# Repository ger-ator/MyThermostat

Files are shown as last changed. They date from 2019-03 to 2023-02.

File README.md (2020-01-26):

# MyThermostat

MyThermostat is a drop-in replacement board for Farho Xana Plus oil heater.

Provided sketch is a thermostat node draft for MySensors network.

## Features
- ATMega328P makes it Arduino compatible.
- RFM69 for extended range.
- ATSHA204 for hardware signing.
- AT25DF512C FOTA programming enabled.
- Onboard DS18B20 for temperature protection purposes.
- 0,96" Oled display.
- Linear power supply, so no pitch noise around bedroom.
- Power SSR with built-in heatsink. No switching noise.
- Uses the original 2x2 keypad for user interaction.

The board is exactly the same form factor as the factory one so it can be mounted without modifying the original frame. Just unplug the old board and drop-in the new one. The goal is to keep heater modifications as low as possible.

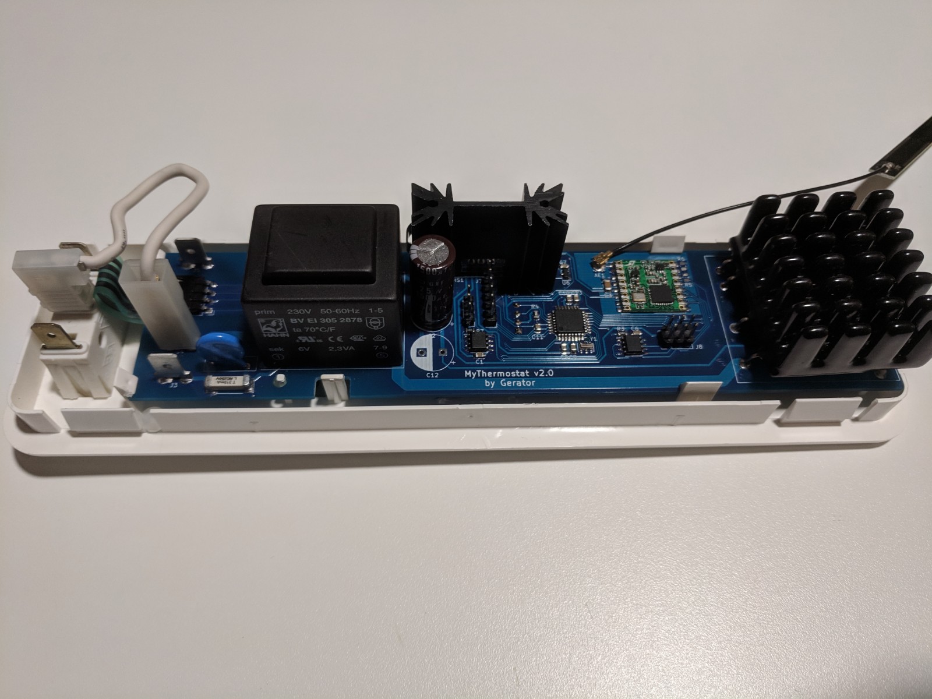
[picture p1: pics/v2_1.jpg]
MyThermostat board


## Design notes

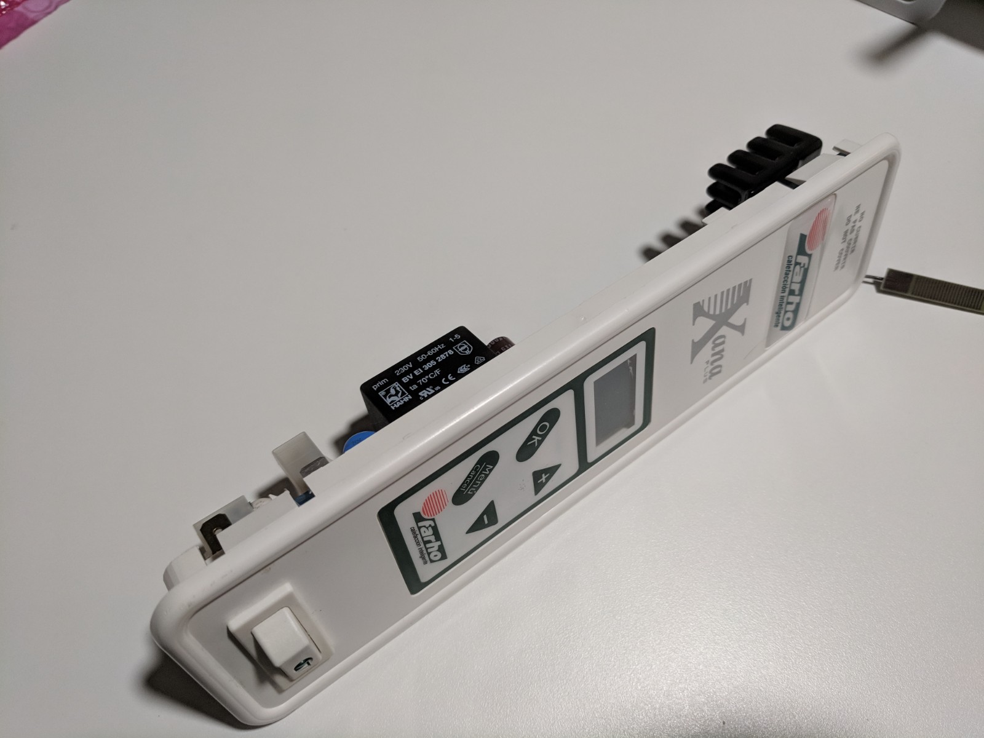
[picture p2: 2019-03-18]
pics/v2_2.jpg

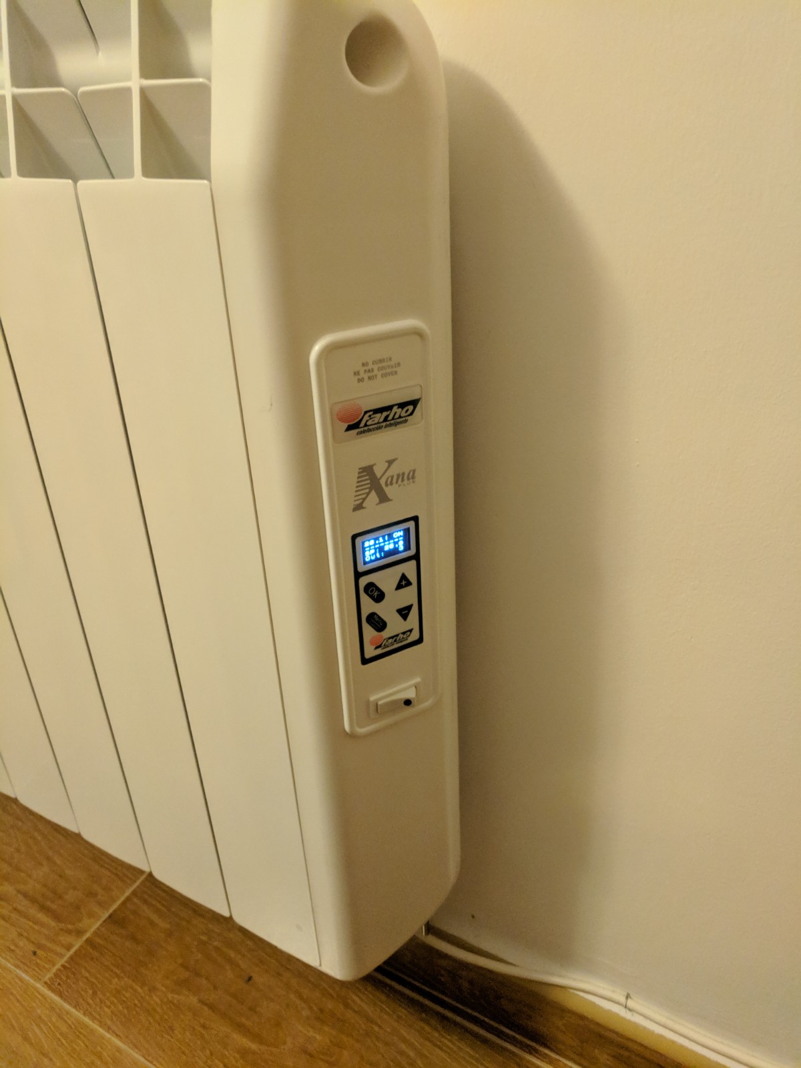
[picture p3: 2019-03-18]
pics/v2_3.jpg

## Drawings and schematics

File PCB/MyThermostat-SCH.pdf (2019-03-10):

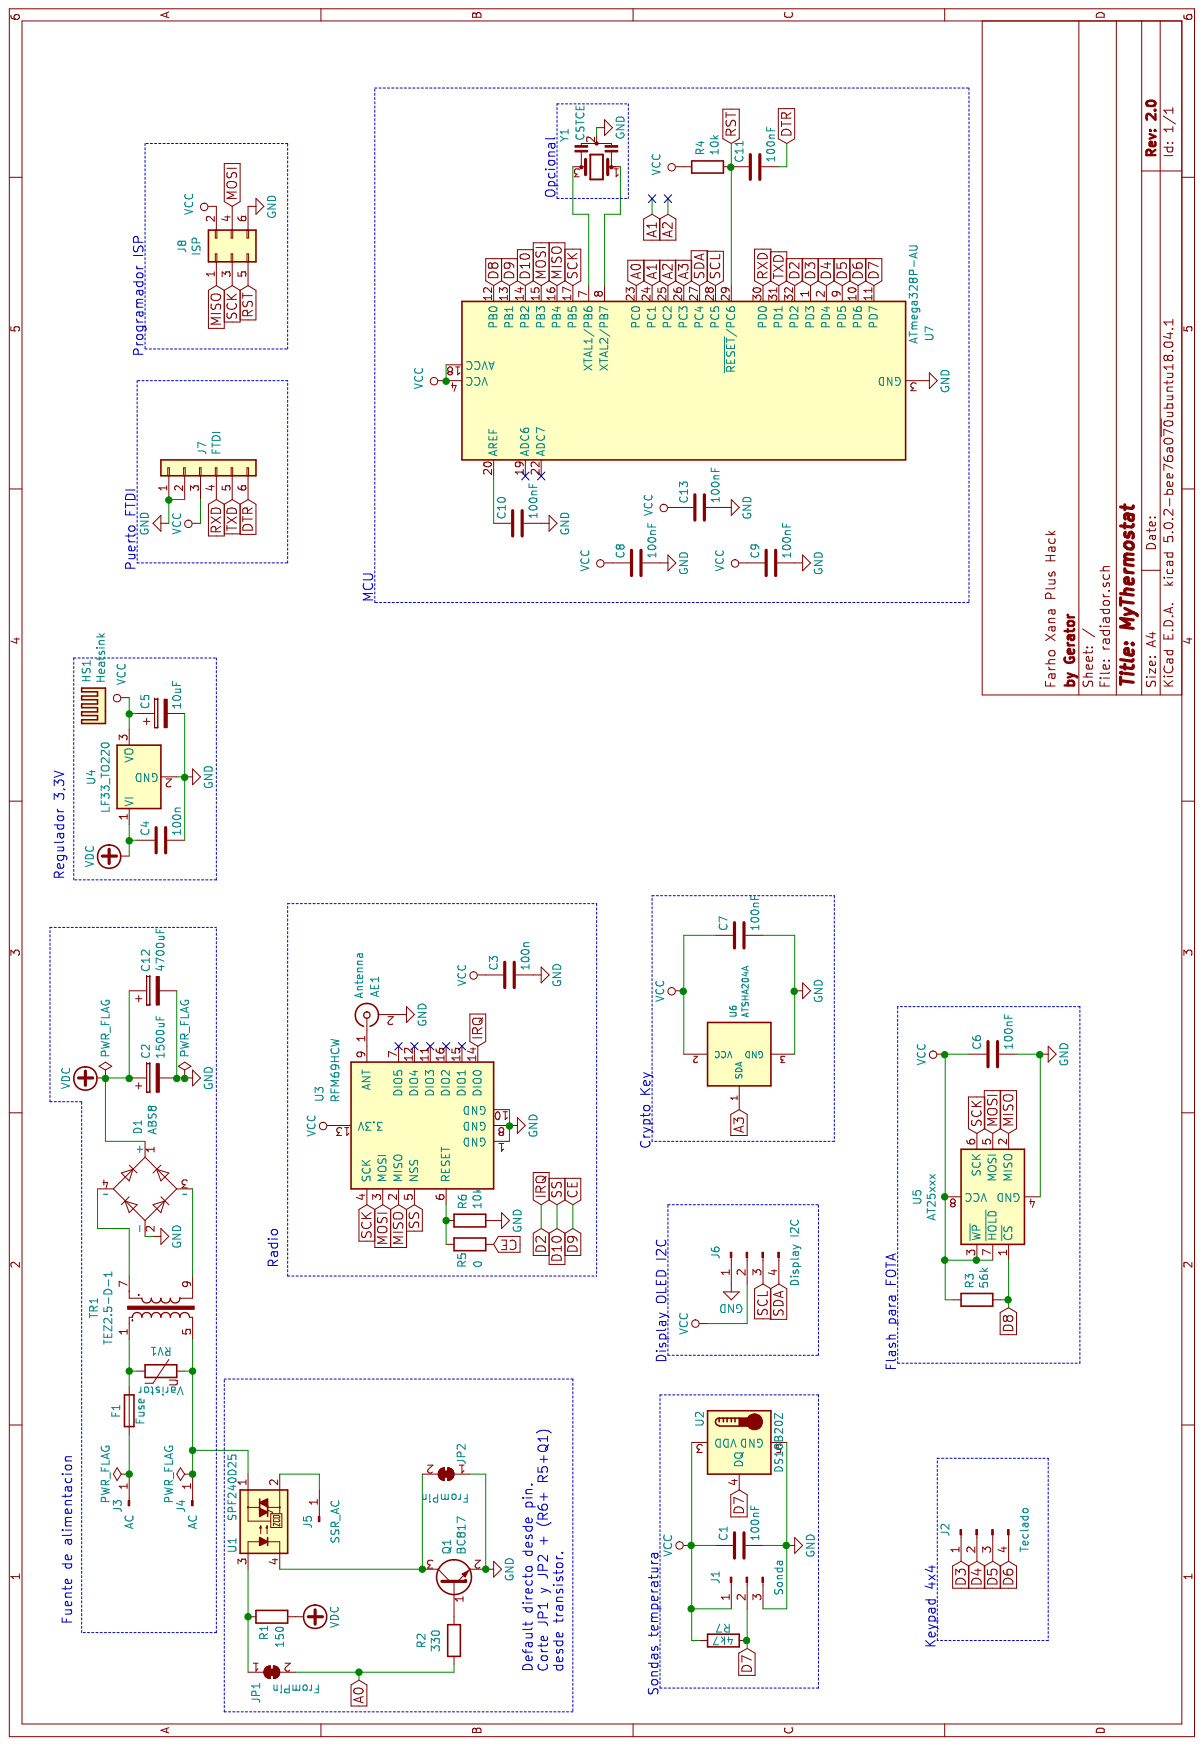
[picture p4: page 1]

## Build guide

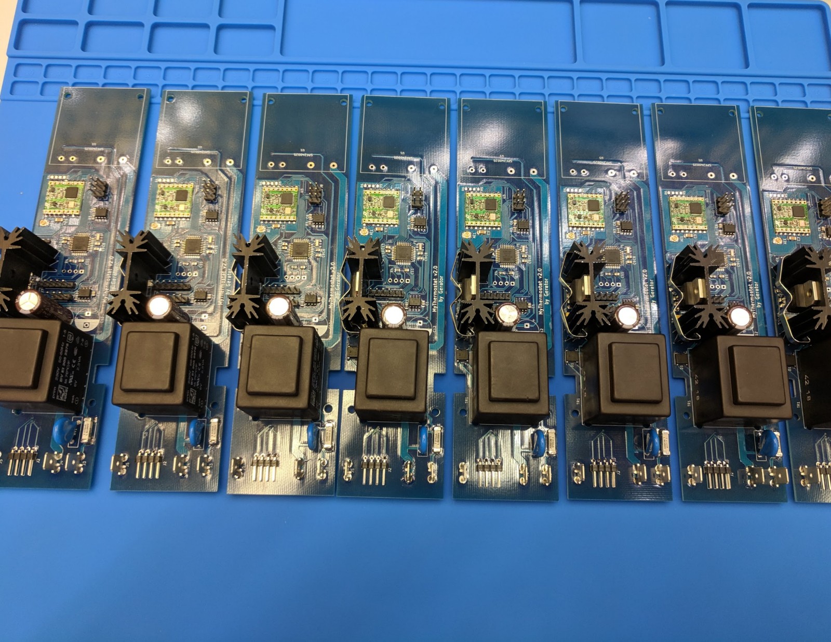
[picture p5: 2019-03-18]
pics/assembling.jpg

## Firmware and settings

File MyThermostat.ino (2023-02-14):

#define SN "MyThermostat"
#define SV "2.2"
// Enable debug prints to serial monitor
//#define MY_DEBUG
// Enable and select radio type attached
#define MY_RADIO_RFM69
#define MY_RFM69_FREQUENCY RFM69_433MHZ
#define MY_IS_RFM69HW
#define MY_RFM69_NEW_DRIVER
#define MY_RFM69_MAX_POWER_LEVEL_DBM (20)
#define MY_RFM69_ATC_TARGET_RSSI_DBM (-75)
#define MY_SIGNAL_REPORT_ENABLED

//Wait gateway for 5sg
#define MY_TRANSPORT_WAIT_READY_MS 5000
// OTA Firmware update settings
#define MY_OTA_FIRMWARE_FEATURE
// Signing setup
#define MY_SIGNING_ATSHA204
#define MY_SIGNING_REQUEST_SIGNATURES
#define CHILD_ID 1

#define MY_SPLASH_SCREEN_DISABLED

#include <MySensors.h>
#include <Keypad.h>
#include "OledDisplay.h"
#include <OneWire.h>
#include <DallasTemperature.h>

/*
 *   Used pins
 */
#define PIN_RELAY A0
#define PIN_TEMP  7

/*
 *   EEPROM addresses for config and state storage.
 */
#define EEPROM_V_SETPOINT 0
#define EEPROM_V_STATUS 4
#define EEPROM_SAFETY_ADDRESS 6
#define EEPROM_CONTROL_ADDRESS 14

/*
 *    DS18B20 temperature sensors.
 */
OneWire oneWire(PIN_TEMP);
DallasTemperature sensors(&oneWire);
DeviceAddress room_sensor, safety_sensor;
float safety_temp, room_temp, setpoint;

typedef enum
{
  IN_HEATER_SENSOR,
  REMOTE_SENSOR
} T_mode;
T_mode room_temp_mode = IN_HEATER_SENSOR;

/*
 *   Display OLED I2C 0,96"
 */
OledDisplay oled;

/*
 *   2x2 Keypad
 */
const byte ROWS = 2;
const byte COLS = 2;
byte rowPins[ROWS] = {5, 3};
byte colPins[COLS] = {6, 4};
char keys[ROWS][COLS] = {
  {'-', '+'},
  {'M', 'O'}
};
Keypad keypad(makeKeymap(keys), rowPins, colPins, ROWS, COLS);
float kp_setpoint;
bool kp_ts_switch;

/*
 *   S_HVAC
 */
MyMessage msg_setpoint(CHILD_ID, V_HVAC_SETPOINT_HEAT);
MyMessage msg_temp(CHILD_ID, V_TEMP);
//MyMessage msg_power_control(CHILD_ID, V_HVAC_SPEED); //Lo puedo usar para control AUTO o MANUAL
MyMessage msg_status(CHILD_ID, V_HVAC_FLOW_STATE); //Lo puedo usar para encender y apagar
bool ts_switch; //true: ON - false: OFF

typedef enum
{
  NONE,
  RECEIVED,
  PENDING
} Ack;
Ack setpoint_ack, ts_switch_ack = NONE;

/*
 *   Temporizado
 */
#define DUTY_CYCLE 10000 //ms
#define DALLAS_RATE 2000 //ms
#define BACKLIGHT_TIME 17100 //ms
#define REFRESH_RATE_2MIN 120000 //ms
#define REFRESH_RATE_13MIN 780000 //ms
#define REFRESH_RATE_59MIN 3540000 //ms
#define TEMPMODE_FALLBACK 900000 //ms //15MIN

unsigned long timing_cycle;
unsigned long timing_dallas;
unsigned long timing_lcdbacklight;
//unsigned long timing_temp_refresh;
//unsigned long timing_sp_refresh;
unsigned long timing_refresh;
unsigned long timing_ack_request;
unsigned long timing_tempmode_fallback;

/*
 *   Misc
 */
#define REQUEST_ECHO true
#define SP_INCDEC 0.5
bool initialValueSent = false;

void setup()
{
  /*
   *     Last status restore
   */
  setpoint = loadFloat(EEPROM_V_SETPOINT);
  ts_switch = loadState(EEPROM_V_STATUS);
  if (isnan(setpoint)
    || (setpoint < 5.0)
    || (setpoint > 30.0)) setpoint = 20.0;
  
  /*
   *     Load sensor addresses, setup and take first reading.
   *     Setup WaitForConversion for non blocking code.
   */
  for (uint8_t i = 0; i < 8; i++)
  {
    room_sensor[i] = loadState(EEPROM_CONTROL_ADDRESS + i);
    safety_sensor[i] = loadState(EEPROM_SAFETY_ADDRESS + i);
  }
  sensors.begin();
  sensors.setResolution(room_sensor, 12);
  sensors.setResolution(safety_sensor, 9);
  sensors.requestTemperatures();
  sensors.setWaitForConversion(false);
  room_temp = sensors.getTempC(room_sensor);
  safety_temp = sensors.getTempC(safety_sensor);
  
  /*
   *     OLED 0,96" display library setup
   */
  oled.begin(&Adafruit128x64, I2C_ADDRESS);
  oled.setFont(font8x8);
  oled.set2X();
  oled.setEnabled();
  
  /*
   *     Relay output setup
   */
  pinMode(PIN_RELAY, OUTPUT);
  
  /*
   *     Add event listener for 2x2 keypad
   */
  keypad.addEventListener(keypadEvent);
  kp_setpoint = setpoint;
  kp_ts_switch = ts_switch;
  
  /*
   *     Initialize timing counters.
   */
  timing_dallas = timing_cycle = timing_tempmode_fallback = 0;
//  timing_temp_refresh = timing_ack_request = timing_lcdbacklight = timing_sp_refresh = millis();
  timing_ack_request = timing_lcdbacklight = timing_refresh = millis();
  
}

void presentation()
{
  sendSketchInfo(SN, SV);
  present(CHILD_ID, S_HVAC);
}

void loop()
{
  if ((!initialValueSent) || (millis() - timing_refresh >= REFRESH_RATE_13MIN)){
    /*
     * Send initial status to controller.
     */
    send(msg_temp.set(room_temp, 1));
    send(msg_setpoint.set(setpoint, 1));
    send(msg_status.set(ts_switch ? "HeatOn" : "Off"));
    initialValueSent = true;
    timing_refresh = millis();
  }
  /*
   *     Get local temperature sensors reading.
   */
  if (millis() - timing_dallas >= DALLAS_RATE) {
    if (room_temp_mode == IN_HEATER_SENSOR)
      room_temp = sensors.getTempC(room_sensor);
    safety_temp = sensors.getTempC(safety_sensor);
    sensors.requestTemperatures();
    timing_dallas = millis();
  }
  
  /*
   *     Fallback to internal sensor if no data received for X time.
   */
  if (millis() - timing_tempmode_fallback >= TEMPMODE_FALLBACK) {
    room_temp_mode = IN_HEATER_SENSOR;
  }
  
  /*
   *     Relay actuation.
   */
  if (millis() - timing_cycle >= DUTY_CYCLE) {
    digitalWrite(PIN_RELAY,
                 (ts_switch &&
                 safety_temp < 55 &&
                 room_temp < setpoint) ? HIGH : LOW);
    timing_cycle = millis();
  }
  
  /*
   *     Send room temperature to controller.
   */
//  if (millis() - timing_temp_refresh >= REFRESH_RATE_13MIN) {
//    send(msg_temp.set(room_temp, 1));
//    timing_temp_refresh = millis();
//  }
  /*
   *     Send setpoint to controller.
   */
//  if (millis() - timing_sp_refresh >= REFRESH_RATE_59MIN) {
//    send(msg_setpoint.set(setpoint, 1));
//    timing_sp_refresh = millis();
//  }
  
  /*
   *     Resend data that requested ack when ack is lost.
   */
  if (millis() - timing_ack_request >= REFRESH_RATE_2MIN) {
    if (setpoint_ack == PENDING) {
      send(msg_setpoint.set(setpoint, 1), REQUEST_ECHO);
    }
    if (ts_switch_ack == PENDING)  {
      send(msg_status.set(ts_switch), REQUEST_ECHO);
    }
    timing_ack_request = millis();
  }
  
  /*
   *     Display refresh and turn off when idle for BACKLIGHT_TIME ms.
   *     When display is turned off modified data is stored.
   */
  if (oled.isEnabled()) {
    oled_refresh();
    if (millis() - timing_lcdbacklight >= BACKLIGHT_TIME) {
      setSetpoint(kp_setpoint, true);
      setStatus(kp_ts_switch, true);
      oled.setDisabled();
    }
  }
  
  /*
   *     Read the keypad.
   *     Further actions on event function.
   */
  keypad.getKey();
}

void keypadEvent(KeypadEvent key) {
  switch (keypad.getState()) {
    case PRESSED:
      timing_lcdbacklight = millis();
      if (!oled.isEnabled()) {
        kp_setpoint = setpoint;
        kp_ts_switch = ts_switch;
        oled.setEnabled();
        break;
      }
      
      switch (key) {
        case '+': kp_setpoint = kp_setpoint + SP_INCDEC; break;
        case '-': kp_setpoint = kp_setpoint - SP_INCDEC; break;
        case 'M': break;
        case 'O': kp_ts_switch = !kp_ts_switch; break;
      }
      break;
  }
}

void oled_refresh (void) {
  oled.home();
  oled.print(room_temp, 1); oled.println(kp_ts_switch ? F("| ON") : F("|OFF"));
  oled.println(F("--------"));
  oled.print(F("SP: ")); oled.println(kp_setpoint, 1);
  oled.print(room_temp_mode == IN_HEATER_SENSOR ? F("I  ") : F("R  "));
  if (safety_temp > 55) oled.println(F("HI-HI"));
  else if (safety_temp > 50) oled.println(F("   HI"));
  else oled.println(F("   OK"));
}

/*
 *   Turn float into 4 byte and store in EEPROM.
 */
void saveFloat(const uint8_t pos, const float value) {
  union float_bytes {
    float val;
    byte bytes[sizeof(float)];
  } data;
  data.val = value;
  for (int i = 0; i < sizeof(float); i++) {
    saveState(pos + i, data.bytes[i]);
  }
}

/*
 *   Load 4 bytes from EEPROM and turn to float.
 */
float loadFloat (const uint8_t pos) {
  union float_bytes {
    float val;
    byte bytes[sizeof(float)];
  } data;
  for (int i = 0; i < sizeof(float); i++) {
    data.bytes[i] = loadState(pos + i);
  }
  return data.val;
}

/*
 *   setSetpoint
 */
bool setSetpoint (float new_setpoint, bool fromKeyPad) {
  if ((new_setpoint != setpoint) && (new_setpoint >= 5.0) && (new_setpoint <= 30.0)) {
    setpoint = new_setpoint;
    if (fromKeyPad) {
      send(msg_setpoint.set(setpoint, 1), REQUEST_ECHO);
      setpoint_ack = PENDING;
    }
    saveFloat(EEPROM_V_SETPOINT, setpoint);
    return true;
  }
  return false;
}

/*
 *   setStatus
 */
bool setStatus (bool v_status, bool fromKeyPad) {
  if (v_status != ts_switch) {
    ts_switch = v_status;
    if (fromKeyPad) {
      send(msg_status.set(ts_switch ? "HeatOn" : "Off"), REQUEST_ECHO);
      ts_switch_ack = PENDING;
    }
    saveState(EEPROM_V_STATUS, ts_switch);
    return true;
  }
  return false;
}

void receive(const MyMessage &message)
{
  switch (message.type) {
    case V_HVAC_SETPOINT_HEAT: {
      if (message.isAck())
        setpoint_ack = RECEIVED;
      else
        setSetpoint(message.getFloat(), false);
      break;
    }
    case V_HVAC_FLOW_STATE: {
      if (message.isAck())
        ts_switch_ack = RECEIVED;
      else {
        char *payload =  message.getString();
        if (strcmp(payload, "Off") == 0) setStatus(false, false);
        else if(strcmp(payload, "HeatOn") == 0) setStatus(true, false);
        else send(msg_status.set(ts_switch ? "HeatOn" : "Off"));
      }
      break;
      }
//    case V_HVAC_SPEED: {
//      char *payload =  message.getString();
//      if (strcmp(payload, "Min") == 0) ;
//      else if(strcmp(payload, "Normal") == 0) ;
//      else if(strcmp(payload, "Max") == 0) ;
//      else if(strcmp(payload, "Auto") == 0) ;
//      break;
//    }
    case V_TEMP: {
      room_temp_mode = REMOTE_SENSOR;
      timing_tempmode_fallback = millis();
      room_temp = message.getFloat();
      break;  
    }
  }
}

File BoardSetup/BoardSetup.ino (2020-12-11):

//Fixed node ID
#define MY_NODE_ID 8

// Enable and select radio type attached
#define MY_RADIO_RFM69
#define MY_RFM69_FREQUENCY RFM69_433MHZ
#define MY_IS_RFM69HW
#define MY_RFM69_NEW_DRIVER

//Espera 5sg y entra al loop
#define MY_TRANSPORT_WAIT_READY_MS 5000

// OTA Firmware update settings
#define MY_OTA_FIRMWARE_FEATURE
#define OTA_WAIT_PERIOD 300
#define FIRMWARE_MAX_REQUESTS 2
#define MY_OTA_RETRY 2

// Signing setup
#define MY_SIGNING_ATSHA204
#define MY_SIGNING_REQUEST_SIGNATURES

#include <MySensors.h>
#include <DallasTemperature.h>

#define EEPROM_SAFETY_ADDRESS 6
#define EEPROM_CONTROL_ADDRESS 14

#if MY_NODE_ID == 1
DeviceAddress ControlTemp = { 0x28, 0xFF, 0x16, 0x36, 0x86, 0x16, 0x04, 0x7D };
DeviceAddress SafetyTemp = { 0x28, 0x52, 0x47, 0x81, 0x0A, 0x00, 0x00, 0xDA };
#elif MY_NODE_ID == 2
DeviceAddress ControlTemp = { 0x28, 0xFF, 0x56, 0xE3, 0x86, 0x16, 0x05, 0x4A };
DeviceAddress SafetyTemp = { 0x28, 0x72, 0x45, 0x81, 0x0A, 0x00, 0x00, 0xEF };
#elif MY_NODE_ID == 3
DeviceAddress ControlTemp = { 0x28, 0xFF, 0x90, 0x99, 0x85, 0x16, 0x03, 0x7E };
DeviceAddress SafetyTemp = { 0x28, 0xD1, 0x42, 0x81, 0x0A, 0x00, 0x00, 0xBB };
#elif MY_NODE_ID == 4
DeviceAddress ControlTemp = { 0x28, 0xFF, 0xB1, 0x78, 0x71, 0x17, 0x03, 0x5A };
DeviceAddress SafetyTemp = { 0x28, 0x34, 0x47, 0x81, 0x0A, 0x00, 0x00, 0xAB };
#elif MY_NODE_ID == 5
DeviceAddress ControlTemp = { 0x28, 0xFF, 0x2D, 0xC0, 0x71, 0x17, 0x03, 0x41 };
DeviceAddress SafetyTemp = { 0x28, 0xA2, 0x59, 0x81, 0x0A, 0x00, 0x00, 0x76 };
#elif MY_NODE_ID == 6
DeviceAddress ControlTemp = { 0x28, 0xFF, 0x65, 0x0B, 0x80, 0x17, 0x04, 0x9E };
DeviceAddress SafetyTemp = { 0x28, 0xB3, 0x52, 0x81, 0x0A, 0x00, 0x00, 0x6A };
#elif MY_NODE_ID == 7
DeviceAddress ControlTemp = { 0x28, 0xFF, 0xC9, 0xA6, 0x71, 0x17, 0x03, 0x1D };
DeviceAddress SafetyTemp = { 0x28, 0xF8, 0x90, 0x80, 0x0A, 0x00, 0x00, 0xC9 };
#elif MY_NODE_ID == 8
DeviceAddress ControlTemp = { 0x28, 0xFF, 0x9F, 0x48, 0x71, 0x17, 0x03, 0x48 };
DeviceAddress SafetyTemp = { 0x28, 0x4B, 0x8B, 0x80, 0x0A, 0x00, 0x00, 0x9B };
#endif

void setup() {
  for (uint8_t i = 0; i < 8; i++)
  {
    saveState(EEPROM_CONTROL_ADDRESS + i, ControlTemp[i]);
    saveState(EEPROM_SAFETY_ADDRESS + i, SafetyTemp[i]);
  }
}

void loop() {
  
}

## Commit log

2019-03-10 Add schematic and gerbers v2.0
    [MyThermostat-B.Cu.gbl, MyThermostat-B.Mask.gbs, MyThermostat-B.Paste.gbp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]
2019-03-10 Update proof of concept sketch for v2.0 board.
2019-04-07 Improve board setup sketch.
2019-05-03 Lower protection temperature.
2019-11-22 Changed to new RFM69 driver. Code cleanup. Eliminated resend of setpoint to controller...
2019-12-05 Dropped PID functionality as it seems it doesn't make sense.
    [MyThermostat.ino]
2019-12-08 Add second power level for better room temp control.
2019-12-08 Fix for correct display when DUTY_CYCLE changes.
    [MyThermostat.ino]
2019-12-25 Prevent delay in safety protection.
    [MyThermostat.ino]
2019-12-26 Revert "Prevent delay in safety protection." Better 10sec delay than fast switching SSR when safety_temp is close to 55. Not worth implement deadband.
    This reverts commit a4756e7fac9a49f84b37c1e0801480a3c3e09a12.
    [MyThermostat.ino]
2019-12-27 Reimplemented power control. Using PID to hold temperature.
2020-01-09 Test ended. Revert "Fine tune some parameters."
    This reverts commit 118efa3ddb429ee8a7eabac03e72f274cb82b639.
    [MyThermostat.ino]
2020-01-09 Test ended. Revert "Reimplemented power control. Using PID to hold temperature."
    This reverts commit f508b738b752b9c6491f98e50082bde7b0de10b8.
    [MyThermostat.ino]
2020-01-09 Initial remote sensor support.
2020-08-18 Revert Ack to Echo update. Going back to MySensors 2.2.0 due to RFM69 issues.
    [MyThermostat.ino]
2020-10-02 Disable ATC mode as it messes up comms. Set tx power level ti 20dBm. Send setpoint hourly as expected by domoticz.
2020-12-11 Updated sensors adresses.
2023-02-14 Añadido soporte para Home Assistant
